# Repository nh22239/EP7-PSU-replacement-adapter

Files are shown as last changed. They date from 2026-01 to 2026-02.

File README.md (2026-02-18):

# EP7 adapter

A friend of mine found a Studiomaster Trilogy 166 mixing desk at a tip sale, unfortunately it came without it's original power supply. My friend sent me the electrical diagrams for the power supply and asked me if I could build one, but that would be too much of a job, so I offered to make a MacGyver version.

## Requirements

The original power supply, called EP7, takes mains power and spits out +/-17V (900mA) and 48V (100mA) through a 5-pin 240-degree dip jack. This is somewhat awkward, but I have a solution....



## Solution

I will take two +17V DC power supplies, and one +48V power supply, and build a circuit that combines these into the dip jack that my friend's mixing desk wants.



I have included a few additional features here, namely noise reduction on each power line, an on/off switch to help avoid lobsided power, a delay on the 48V line to stop any pops from this supply, and some resistors to discharge everything when powered off.

Some of these additions may be useless, and there may be some sensible features that I have failed to put in, but at least this shouldn't break any of my friend's gear.

EP7 PSU replacement



## UPDATE 18/02/25

Big oops... capacitor C6 is the wrong way round here, it exploded on my finger when I plugged it in... In addition, the DC jacks I bought are wired differently to the standard ones in KiCad... so here I am with a stinging finger, cutting tracks and throwing new wires. Updated circuit diagram to come.

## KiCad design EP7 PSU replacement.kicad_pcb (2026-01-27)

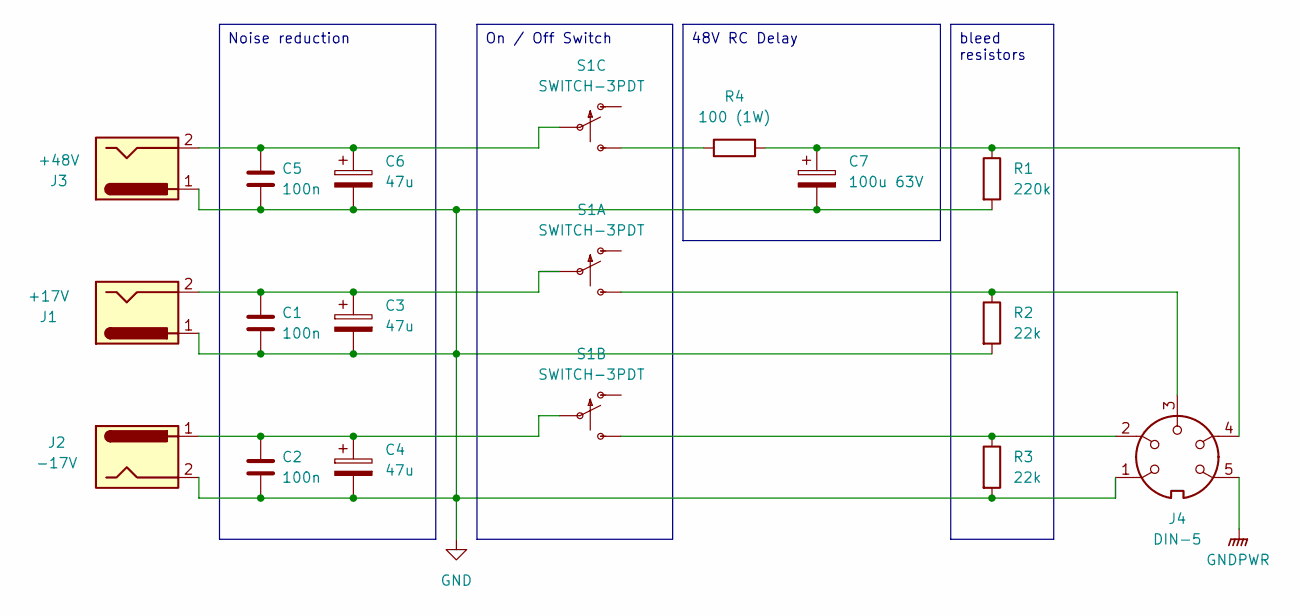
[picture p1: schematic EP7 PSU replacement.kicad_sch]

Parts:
C1, C2, C5: 100n; C_Axial_L3.8mm_D2.6mm_P7.50mm_Horizontal
C3, C4, C6: 47u; CP_Radial_D4.0mm_P2.00mm
C7: 100u 63V; CP_Radial_D4.0mm_P2.00mm
J1: +17V; BarrelJack_Horizontal
J2: -17V; BarrelJack_Horizontal
J3: +48V; BarrelJack_Horizontal
J4: DIN-5; SolderWire-1sqmm_1x05_P5.4mm_D1.4mm_OD2.7mm_Relief
R1: 220k; R_Axial_DIN0207_L6.3mm_D2.5mm_P7.62mm_Horizontal
R2, R3: 22k; R_Axial_DIN0207_L6.3mm_D2.5mm_P7.62mm_Horizontal
R4: 100 (1W); R_Axial_DIN0207_L6.3mm_D2.5mm_P7.62mm_Horizontal
S1: SWITCH-3PDT; STOMP-SWITCH-3PDT

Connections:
GND: C1.2, C2.2, C3.2, C4.2, C5.2, C6.2, C7.2, J1.1, J2.2, J3.1, J4.1, R1.2, R2.2, R3.2
GNDPWR: J4.5
unnamed: C7.1, J4.4, R1.1, R4.2
unnamed: C1.1, C3.1, J1.2, S1.P$2
unnamed: J4.3, R2.1, S1.P$3 (S)
unnamed: C2.1, C4.1, J2.1, S1.P$5
unnamed: J4.2, R3.1, S1.P$6 (S)
unnamed: C5.1, C6.1, J3.2, S1.P$8
unnamed: R4.1, S1.P$9 (S)

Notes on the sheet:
Noise reduction
48V RC Delay
bleed resistors
On / Off Switch

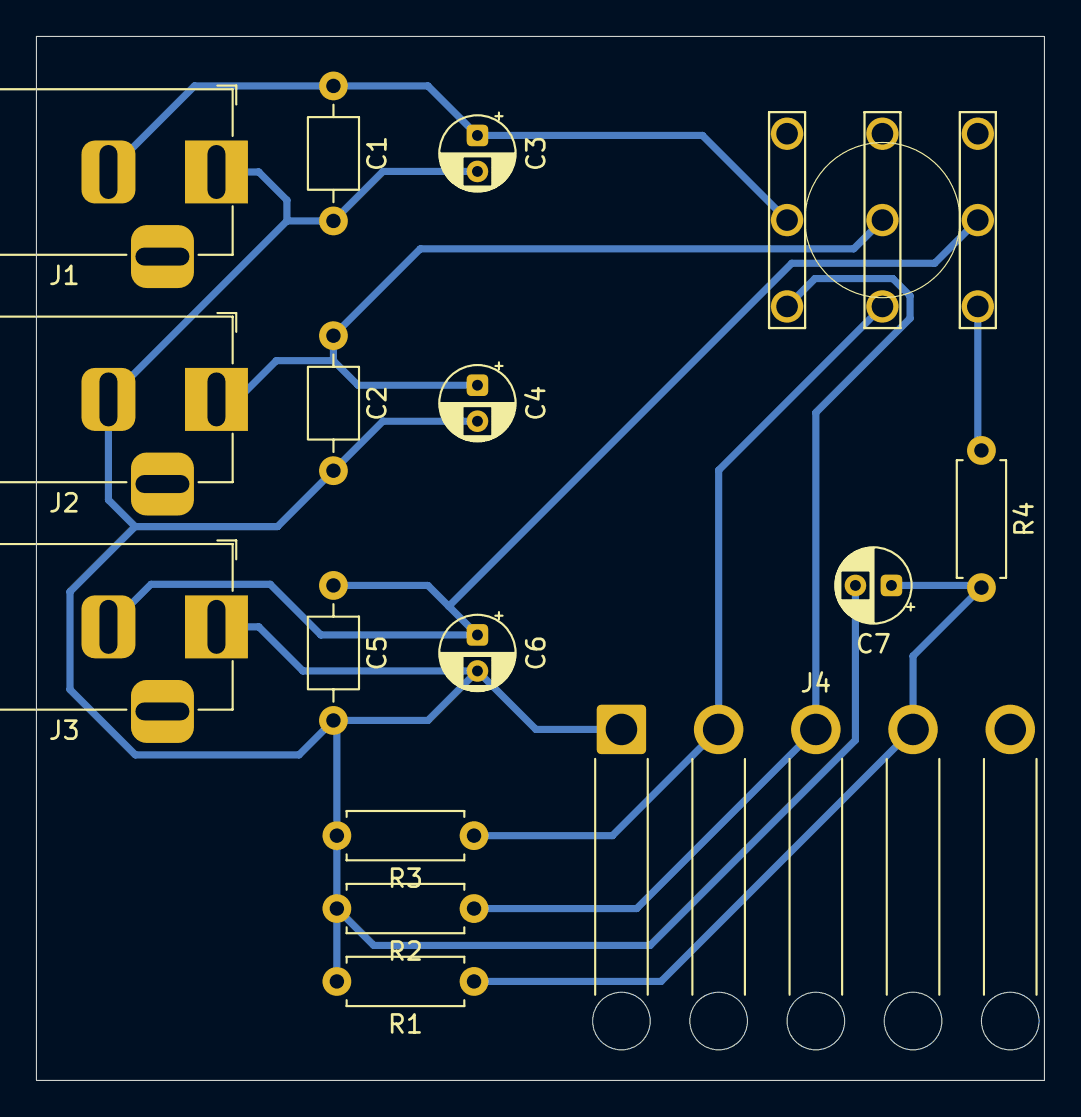
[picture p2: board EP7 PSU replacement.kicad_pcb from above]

Board: 2 copper layers, 56.0 x 58.0 mm, 16 parts (0 on the bottom side), 8 nets.
